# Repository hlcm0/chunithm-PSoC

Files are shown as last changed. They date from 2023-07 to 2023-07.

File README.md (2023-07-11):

# chunithm-PSoC
一个可参考的chunithm手台使用PSoC芯片的例子

## 大体结构
* 使用RP2040开发板作为主控芯片
* 两块PSoC4（cy8c4245axi-483）作为触摸芯片，通过I2C与RP2040通讯
* 由于RP2040的ADC外设数量不足，使用74hc4051多路模拟复用器芯片来轮询六个红外接收
* 使用yubideck的io进行通讯

## 特别感谢
* 凌鸽在触摸干扰调试和Air调试上提供的帮助（Air校准部分参考自LINGNITHM项目）
* yubideck开放的io协议

## 关于PSoC
* 需要的软件：PSoC Creator
* PSoC Creator的使用可以观看youtube上的PSoC101相关教程，也可以来三连支持一下我在bilibili上传的渣翻的[PSoC101教程](https://www.bilibili.com/video/BV1js4y1y7VQ/)（
* PSoC4的烧录也许可以使用普通的SWD烧录器（如jlink，daplink等），但我并没摸索出来。目前已知可行的办法：</br>
1.使用kitprog（可从CY8CKIT-147上掰下来）</br>
2.使用miniprog（将近一千块钱，好贵）</br>
3.使用arduino作为其SWD烧录器（我没试过，不过应该可以），详见项目[PSoC4_HSSP_Arduino](https://github.com/k4zuk/PSoC4_HSSP_Arduino)</br>

## 备注
* pid，vid，设备名和制造商名可以在代码中修改了，而不需要修改boards.txt
* 受预算和个人精力限制，本项目的cad以及支架设计极为落后，所以仅供软硬件方案参考，可参考更完善成熟的方案，如LINGNITHM、GSK等
* 由于右边Air在PCB上没空间走线过去，所以我使用了一根排线飞过去，这就是pcb原理图中有四个XH插座的原因（（可以看实物图）
* 可以将I2C通讯更改为UART通讯来达成更高的传输速度
* 板子上加了一个EEPROM，连接到了RP2040的I2C0外设，可用于保存用户配置（未实现），因为RP2040没有自带EEPROM
* 暂未编写灯光反馈功能
* 如果想适配原生串口，需要修改TinyUSB库的部分代码来删除其中的DTR信号检查
* 两个芯片之间通过left_ready（左芯片准备好开始下一次扫描），right_start（右芯片开始下一次扫描）两个信号线来保证两个芯片的同步，从而防止扫描的干扰。可以利用上两个PSoC上剩余空闲的引脚来实现其他功能（如PSoC的复位，数据传输等等）
* 单次扫描周期目前实测为23ms，可能需要修改PSoC代码的部分配置来达成更高的扫描速度，详见[CapSense Design Guide](https://www.infineon.com/dgdl/Infineon-AN85951_PSoC_4_CapSense_Design_Guide-ApplicationNotes-v27_00-CN.pdf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)

## 实物图


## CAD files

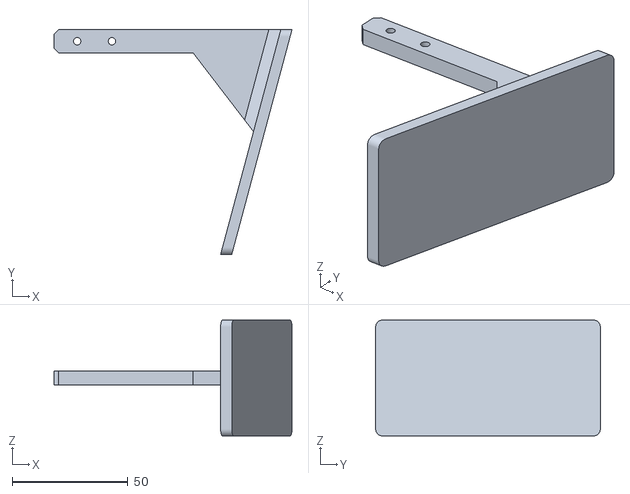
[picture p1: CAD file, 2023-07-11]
3D model/Air支架.stl
102.7 x 96.9 x 50.0

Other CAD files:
CAD/磨砂亚克力导光板（2mm）.dwg
CAD/光面亚克力（1mm）.dwg

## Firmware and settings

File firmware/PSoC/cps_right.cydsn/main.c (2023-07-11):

/* ========================================
 *
 * Copyright YOUR COMPANY, THE YEAR
 * All Rights Reserved
 * UNPUBLISHED, LICENSED SOFTWARE.
 *
 * CONFIDENTIAL AND PROPRIETARY INFORMATION
 * WHICH IS THE PROPERTY OF your company.
 *
 * ========================================
*/
#include "project.h"
#include "stdio.h"
#include "stdlib.h"

#define start 1
#define running 0

int main(void)
{
    struct touchval
    {
        uint16 baseline[16];
        uint16 raw[16];                                         
    } touchval;
    uint8_t i2cbuf[64];

    CyGlobalIntEnable; /* Enable global interrupts. */

    CapSense_Start();
    CapSense_InitializeAllBaselines();
    CapSense_ScanEnabledWidgets();
    
    I2C_Start();
    I2C_EzI2CSetBuffer1( 64, 1, i2cbuf );

    for(;;)
    {

        if( ! CapSense_IsBusy() )
        {
            for (int i=0;i<16;i++)
            {
                touchval.baseline[i] = CapSense_GetBaselineData(i);
                touchval.raw[i] = CapSense_ReadSensorRaw(i);
            }
            memcpy(i2cbuf, &touchval, 64);
            CapSense_UpdateEnabledBaselines();
            while (left_ready_in_Read() != 1) //等待另一个PSoC准备好开始下一次扫描
            {
                CyDelayUs(1);
            }
            CapSense_ScanEnabledWidgets();
            right_start_out_Write(start); //向right_start信号线写入1表明扫描开始，使另一个PSoC也开始扫描
            CyDelayUs(50); //延迟50微秒确保另一个PSoC收到信号
            right_start_out_Write(running); //向right_start信号线写入0表明正在扫描，请勿进行下一次扫描
        }
    }
}

/* [] END OF FILE */

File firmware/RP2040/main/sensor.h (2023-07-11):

#include <Wire.h>
#include "data.h"

//Touch
#define CLAMP(val, lo, hi) (val < lo ? lo : (val > hi ? hi : val))
#define touch_addr0 0x08 //第一个（左边）芯片的I2C地址
#define touch_addr1 0x09

struct touchval touchval0;
struct touchval touchval1;
uint8_t touchdata[32];

const uint8_t sensorPinMap0[16] = {0,1,2,3,4,5,6,7,9,8,11,10,13,12,15,14}; //第一个触摸芯片引脚到实际区域的映射数组
const uint8_t sensorPinMap1[16] = {16,17,18,19,20,21,22,23,25,24,27,26,29,28,31,30}; //第二个触摸芯片引脚到实际区域的映射数组

void touchInit()
{
  Wire1.setSDA(18);
  Wire1.setSCL(19);
  Wire1.setClock(1000000);
  Wire1.begin();
}

void updateSensorValue()
{
  uint8_t buffer[64];
  //获取第一个PSoC的数据
  Wire1.requestFrom(touch_addr0, 64);
  uint8_t c = 0;
  while (Wire1.available()) {
    buffer[c] = Wire1.read();
    c ++;
  }
  memcpy(&touchval0, buffer, 64);
  //获取第二个PSoC的数据
  Wire1.requestFrom(touch_addr1, 64);
  c = 0;
  while (Wire1.available()) {
    buffer[c] = Wire1.read();
    c ++;
  }
  memcpy(&touchval1, buffer, 64);
}

void updateTouchData()
{
  int temp;
  for (int i=0; i<16; i++)
  {
    temp = touchval0.raw[i] - touchval0.baseline[i];
    temp = temp / 3 - 15; //这部分的具体处理要随实际情况而定
    touchdata[sensorPinMap0[i]] = CLAMP(temp, 0, 255);
  }
  for (int i=0; i<16; i++)
  {
    temp = touchval1.raw[i] - touchval1.baseline[i];
    temp = temp / 3 - 15;
    touchdata[sensorPinMap1[i]] = CLAMP(temp, 0, 255);
  }
}

uint8_t getTouchData(uint8_t sensorNum)
{
  return touchdata[sensorNum];
}

//Air
#define IR_TX0 0
#define IR_TX1 1
#define IR_TX2 2
#define IR_TX3 3
#define IR_TX4 4
#define IR_TX5 5

#define IR_RX_ADD0 20
#define IR_RX_ADD1 21
#define IR_RX_ADD2 22

#define IR_ADC 26

#define SAMPLES_NUM 200 //校准阈值时采样次数

float pressSensitivity=0.3; //按下灵敏度设定
float releaseSensitivity=0.2; //松开灵敏度设定，比pressSensitivity稍低，防止在阈值附近时结果输出的抖动
uint8_t airVal = 0;
int readings[6] = {0}; //传感器读数
int pressThreshold[6] = {0}; //按下阈值
int releaseThreshold[6] = {0}; //松开阈值
int maxOnReadings[6] = {0}; //LED亮起时ADC读数的最大值
int minOffReadings[6] = {0}; //LED灭时ADC读数的最小值（借鉴自Lingnithm项目）
int mapg[6] = {1,0,3,2,5,4}; //传感器物理位置到yubideck报告比特位置的映射

void airInit()
{
  pinMode(IR_TX0,OUTPUT); //初始化TX端输出引脚
  pinMode(IR_TX1,OUTPUT);
  pinMode(IR_TX2,OUTPUT);
  pinMode(IR_TX3,OUTPUT);
  pinMode(IR_TX4,OUTPUT);
  pinMode(IR_TX5,OUTPUT);

  pinMode(IR_RX_ADD0,OUTPUT); //初始化RX端地址输出引脚
  pinMode(IR_RX_ADD1,OUTPUT);
  pinMode(IR_RX_ADD2,OUTPUT);

  pinMode(IR_ADC,INPUT); //初始化RX端ADC输入引脚
  analogReadResolution(12); //将ADC分辨率设为12bits
}

void airThresholdInit()
{
  gpio_clr_mask(7<<20); // 7即0b111，左移到以gpio20为起始，使用clr_mask函数将20，21，22都设置为低电平
  //LED关闭时采集环境数值
  for (int i = 0; i < SAMPLES_NUM; i++)
  {
    for (int j = 0; j < 6; j++)
    {
      gpio_set_mask(j<<20); // 将对应引脚置高来在ADD引脚上输出地址值
      delayMicroseconds(20); // 保险起见的延迟（
      readings[j] = analogRead(IR_ADC);
      if (readings[j] < minOffReadings[j] || minOffReadings[j] == 0)
      {
        minOffReadings[j] = readings[j];
      }
      gpio_clr_mask(j<<20); // 将对应引脚置低电平
    }
  }

  //LED on
  for (int i = 0; i < SAMPLES_NUM; i++)
  {
    for (int j = 0; j < 6; j++)
    {
      digitalWrite(j,HIGH);
      gpio_set_mask(j<<20);
      delayMicroseconds(400); //用的发射管比较差，要400微秒才能保证当前LED完全开启和上一个完全关断（所以将Air更新放到core1去了，防止阻塞主进程），可根据实际情况调节
      readings[j] = analogRead(IR_ADC);
      if (readings[j] > maxOnReadings[j])
      {
        maxOnReadings[j] = readings[j];
      }
      digitalWrite(j,LOW);
      gpio_clr_mask(j<<20);
    }
  }

  //Set up threshold value
  float temp;
  for (int i = 0; i < 6; i++)
  {
    //Press threshold
    temp = (minOffReadings[i] - maxOnReadings[i]) * pressSensitivity + maxOnReadings[i];
    pressThreshold[i] = temp;
    temp = (minOffReadings[i] - maxOnReadings[i]) * releaseSensitivity + maxOnReadings[i];
    releaseThreshold[i] = temp;
  }
}

void updateAirVal()
{
  gpio_clr_mask(7<<20);
  for (int i = 0; i < 6; i++)
  {
    digitalWrite(i, HIGH);
    gpio_set_mask(i<<20);
    delayMicroseconds(400);
    readings[i] = analogRead(IR_ADC);
    if (readings[i] >= pressThreshold[i])
    {
      airVal |= 1<<mapg[i];
    }
    if (readings[i] <= releaseThreshold[i])
    {
      airVal &= ~(1<<mapg[i]);
    }
    digitalWrite(i, LOW);
    gpio_clr_mask(i<<20);
  }
}

uint8_t getAirVal()
{
  return airVal;
}

//Button
#define service 11
#define coin 12
#define test 13

uint8_t buttonVal = 0;

void buttonInit()
{
  pinMode(service,INPUT_PULLUP);
  pinMode(coin,INPUT_PULLUP);
  pinMode(test,INPUT_PULLUP);
}

void updateButton()
{
  buttonVal = 0;
  if (digitalRead(service) == LOW)
  {
    buttonVal += 0x02;
  }
  if (digitalRead(coin) == LOW)
  {
    buttonVal += 0x04;
  }
  if (digitalRead(test) == LOW)
  {
    buttonVal += 0x01;
  }
}

uint8_t getButtonVal()
{
  return buttonVal;
}

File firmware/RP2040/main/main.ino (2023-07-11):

#include "sensor.h"
#include "Adafruit_TinyUSB.h"
#include "report.h"
#include "Adafruit_NeoPixel.h"

Adafruit_USBD_HID usb_hid(desc_hid_report, sizeof(desc_hid_report), HID_ITF_PROTOCOL_NONE, 1, true);

void setup() {
  // put your setup code here, to run once:
  touchInit(); //初始化与触摸芯片的I2C通讯
  buttonInit(); //初始化功能键引脚
  TinyUSBDevice.setSerialDescriptor("HLCM"); //设定USB设备序列号
  TinyUSBDevice.setID(0x1973,0x2001); //设定USB设备vid，pid
  TinyUSBDevice.setProductDescriptor("psocnithm"); //设定USB设备产品名
  TinyUSBDevice.setManufacturerDescriptor("HLCM.co"); //设定USB设备制造商名
  usb_hid.setPollInterval(1); //设置最小1ms的回报间隔
  usb_hid.setReportCallback(get_report_callback, set_report_callback); //当电脑向手台发送数据时会调用set_report_callback进行处理
  usb_hid.begin();
  while (!TinyUSBDevice.mounted()) delay(1);  //如果没插入则等待
  while (!usb_hid.ready()) delay(1);
}

struct inputdata data_tx;
struct usb_output_data_1 data_rx_1;
struct usb_output_data_2 data_rx_2;

void loop() {
  // put your main code here, to run repeatedly: 
  updateSensorValue(); //从触摸芯片获取值
  updateTouchData(); //将值处理后放入TouchData数组
  updateButton(); //从按键获取值
  data_tx.IRValue = getAirVal(); //获取AirVal
  data_tx.Buttons = getButtonVal(); //获取按钮值
  for (int i = 0; i < 32; i++)
  {
    data_tx.TouchValue[i] = getTouchData(i); //获取触摸数值
  }
  data_tx.CardStatue = 0;
  for (int i = 0; i < 10; i ++)
  {
    data_tx.CardID[i] = 0; //读卡，未实现
  }

  usb_hid.sendReport(0, &data_tx, sizeof(data_tx)); //发送报告
}

uint16_t get_report_callback (uint8_t report_id, hid_report_type_t report_type, uint8_t* buffer, uint16_t reqlen)
{
  // not used in this example
  (void) report_id;
  (void) report_type;
  (void) buffer;
  (void) reqlen;
  return 0;
}

void set_report_callback(uint8_t report_id, hid_report_type_t report_type, uint8_t const* buffer, uint16_t bufsize)
{
  // This example doesn't use multiple report and report ID
  (void) report_id;
  (void) report_type;

  //buffer即为从电脑收到的数据，首先判断第1byte的数值，来选择解析为data_rx_1还是data_rx_2 (see definition in report.h)
  if (buffer[0] == 0)
  {
    memcpy(&data_rx_1, buffer, bufsize);
  }
  else
  {
    memcpy(&data_rx_2, buffer, bufsize);
  }
}



#define RGBpin 7
Adafruit_NeoPixel panelRGB(33, RGBpin, NEO_GRB + NEO_KHZ800);
void setup1()
{
  airInit(); //对Air相关端口
  airThresholdInit(); //初始化Air阈值
  panelRGB.begin();
  panelRGB.setBrightness(127);
}

uint16_t starthue = 0;
uint16_t hue = 0;
void loop1() {
  // put your main code here, to run repeatedly:

  for (int i = 0; i < 16; i++) {
    if ((data_tx.TouchValue[i*2 + 1] > 40) || (data_tx.TouchValue[i*2] > 40))
    {
      panelRGB.setPixelColor(i*2 + 1, 255, 255, 255);
    }
    else if ((data_tx.TouchValue[i*2 + 1] < 35) && (data_tx.TouchValue[i*2] < 35))
    {
      panelRGB.setPixelColor(i*2 + 1, 0);
    }
    hue += 400;
  }

  panelRGB.show();
  updateAirVal(); //更新AirVal
}
